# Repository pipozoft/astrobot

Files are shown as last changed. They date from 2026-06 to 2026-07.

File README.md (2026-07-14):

# Astrobot

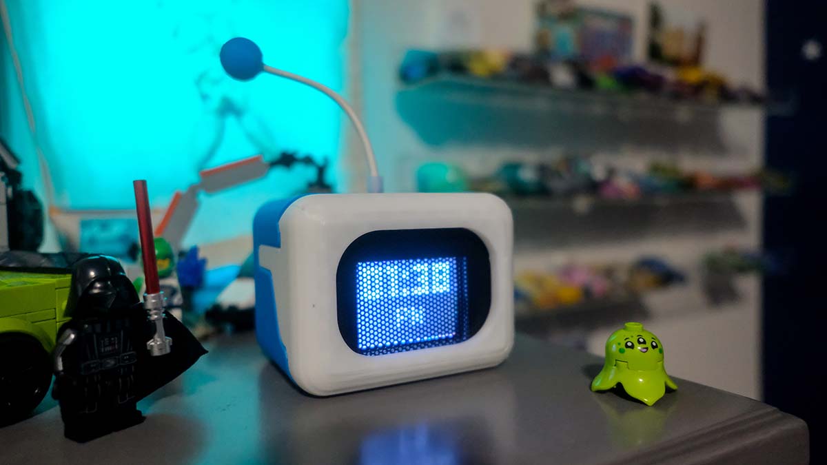
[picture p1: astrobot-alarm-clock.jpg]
Astrobot Alarm Clock


An expressive eye/display bot for the **Inland Nano** (Arduino Nano clone, ATmega328P) with a **1.8" ST7735 TFT**, **HW-084 DS1307 RTC**, and **vibration sensor**.

Cycles between animated pixel-art eyes, a digital clock, and a heartbeat animation on vibration.

## Features

- **Animated eyes** — 5-frame blink/wink sequence with smooth transitions
- **Digital clock** — HH:MM readout with colon blinking, synced from the DS1307 RTC
- **Vibration reaction** — SW-420 triggers a 13-frame heartbeat animation
- **Pixel-art graphics** — All sprites stored in PROGMEM via an external header

## Hardware

| Component | Qty |
|---|-----|
| Inland Nano (Arduino Nano clone) | 1 |
| HW-084 (DS1307 RTC with coin cell) | 1 |
| 1.8" 128×160 TFT (ST7735, 8-pin) | 1 |
| SW-420 vibration sensor | 1 |

See [docs/WIRING_GUIDE.md](docs/WIRING_GUIDE.md) for the full wiring table, pin-reassignment rationale, and enclosure notes.

## Dependencies

Install these via the Arduino Library Manager:

- [Adafruit GFX](https://github.com/adafruit/Adafruit-GFX-Library)
- [Adafruit ST7735](https://github.com/adafruit/Adafruit-ST7735-Library)
- [RTClib](https://github.com/adafruit/RTClib)

## Upload

1. Open `astrobot_hw084.ino` in the Arduino IDE.
2. Select **Tools → Board → Arduino Nano** (or Inland Nano).
3. Select the correct **Processor** (ATmega328P, Old Bootloader if needed).
4. Select the port and upload.

## Project Structure

```
astrobot_hw084/
├── astrobot_hw084.ino      # Main sketch
├── pixel_data.h            # All 23 eye/heart frames as PROGMEM arrays
├── notes.h                 # Pin mappings, constants, and notes
├── HOWITWORKS.md           # Under-the-hood explanation
├── README.md
├── .gitignore
├── 3d/
│   └── astrobot-final-version.3mf   # 3D-printable enclosure
├── docs/
│   └── WIRING_GUIDE.md     # Step-by-step build instructions
├── eyes/
│   ├── ImagesToCArray.py   # PNG → PROGMEM C array converter
│   ├── normal_eye/         # 5 normal eye animation frames (PNG)
│   │   ├── astrobot1-5.png
│   │   └── output.h
│   ├── heart_eye/          # 13 heart eye animation frames (PNG)
│   │   ├── astrobot11-23.png
│   │   └── output.h
│   └── .gitignore
└── music/
    ├── Light MIDI - Astro Bot Theme.mid
    └── Light MIDI - Astro Bot Theme.mp3
```

## Credit

Project based on [Astrobot Clock](https://github.com/Birdy-C/Puzzle-with-3D-Printer/tree/main/Astrobot%20Clock)

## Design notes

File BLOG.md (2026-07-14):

# Building Astrobot: An Arduino Alarm Clock With Personality

Astrobot Alarm Clock

*A gift for my son that became a deep dive into embedded programming, pixel art on a 128x160 screen, and making magic with $25 of parts.*

---

## Why I Built This

My son loves the Astrobot character from the game — the little expressive robot with the big eyes. You can't buy this anywhere. So when I stumbled across [Birdy-C's Astrobot Clock](https://github.com/Birdy-C/Puzzle-with-3D-Printer/tree/main/Astrobot%20Clock) on GitHub, I knew it was the perfect project to build together.

I've built Arduino projects before, so this wasn't my first rodeo. But this one was different — it wasn't just about making something work. It was about making something *charming*. A little bot that looks around, blinks, shows the time, and beats its heart when you knock on it. The kind of thing my son could put on his nightstand and actually want to keep.

I ordered the parts from Microcenter and Amazon, 3D-printed the enclosure, and started hacking.

## What It Is

Astrobot is a small desktop bot with a 1.8" TFT screen as its face. It runs on an Arduino Nano (well, an Inland Nano clone — $8 at Microcenter) and cycles between:

- **Animated eyes** — pixel-art eyes that blink and look left/right
- **A digital clock** — reads the current time from a real-time clock module
- **A heartbeat animation** — when you knock on it, the screen shows beating hearts and plays a melody

There's also an alarm mode that loops the melody at a configurable time. All of this in a 3D-printed enclosure that looks like a little robot head.

### The Parts

| Component | Cost |
|---|---|
| [Inland Nano (ATmega328P)](https://www.microcenter.com/product/615097/inland-nano-development-board-arduino-compatible) | ~$8 |
| 1.8" ST7735 TFT (128x160) | ~$5 |
| HW-084 DS1307 RTC (with CR2032) | ~$3 |
| SW-420 vibration sensor | ~$2 |
| [Adafruit Mini Speaker (1.5W 8 ohm)](https://www.adafruit.com/product/1891) | ~$5 |
| **Total** | **~$23-28** |

All sourced from Microcenter and Amazon. No soldering required if you use a breadboard, or the right wires, though I ended up soldering the speaker wires for a cleaner build.

## How It Works: The Architecture

The entire sketch is built around a **non-blocking state machine** — no `delay()` calls anywhere. This is the single most important design decision in the project, and it's what makes everything feel smooth and responsive.

### The Four States

```
SHOW_EYES  <-->  SHOW_DATE  <-->  VIBRATION_DETECTED  <-->  ALARMING
```

1. **SHOW_EYES** (default) — Displays animated eyes for ~10 seconds. The eyes blink, look left, look right, with random pauses between expressions.

2. **SHOW_DATE** — Renders the current time in 12-hour format with AM/PM. Reads from the DS1307 RTC over I2C. Lasts ~5 seconds.

3. **VIBRATION_DETECTED** — Triggered when the SW-420 sensor fires. Plays a melody and shows a 13-frame beating heart animation.

4. **ALARMING** — When the configured alarm time hits, loops the melody continuously until dismissed by a knock or 60-second timeout.

Each state runs for a set duration using `millis()`, then transitions to the next. The melody player, animation system, and clock display all operate independently — nothing blocks anything else.

### The Pixel Rendering System

This is where it gets interesting. The ATmega328P has **2KB of RAM**. You can't store full animation frames in RAM — a single 128x160 1-bit frame would be 2,560 bytes. More than the entire RAM.

The solution: store everything in **PROGMEM** (flash memory) and render using **diff-based animation**.

Each animation frame is stored as two arrays:
- `white_pixels` — coordinates of pixels to turn ON
- `black_pixels` — coordinates of pixels to turn OFF

Instead of redrawing the entire screen each frame, the renderer only touches the pixels that *changed* between frames. This means each animation step might only draw 5-20 pixels instead of thousands.

Here's what a frame looks like in `pixel_data.h`:

```c
static const PROGMEM byte white_pixels_astrobot1[] = {
  34,3, 35,3, 36,3, 37,3, 38,3, 39,3,  // coordinates of pixels to light up
  // ... more x,y pairs
};
static const byte * const white_pixels[] PROGMEM = { white_pixels_astrobot1, white_pixels_astrobot2, /* ... */ };
```

The Python script `eyes/ImagesToCArray.py` does the heavy lifting — it takes a sequence of PNG sprite frames, computes the pixel diffs between consecutive frames, and outputs the C arrays. I just had to create the pixel art in Aseprite, export the frames, and run the script.

### Eye Mirroring

The bot has two eyes, but I only store one eye's worth of animation data. The right eye is drawn by taking the left eye's pixel coordinates and offsetting them by 80 pixels (x + 80 on the 128px-wide screen).

For the "looking left" vs "looking right" effect, the `_INVERT` variant mirrors the left eye by computing `77 - x`, flipping the eye horizontally. It's a clever trick that halves the data storage needed.

### The Melody Player

The melody is its own mini state machine. Each note in the melody is defined as:

```c
{ frequency_Hz, note_duration_ms, rest_duration_ms }
```

The `updateMelody()` function runs every `loop()` iteration, checking elapsed time against the current note's duration. No blocking, no delays — the melody plays alongside everything else.

The melody itself was converted from a MIDI file of the "Astro Bot Theme" using [ShivamJoker's MIDI-to-Arduino converter](https://github.com/ShivamJoker/MIDI-to-Arduino). Just drop the MIDI in, get a C array out.

## The Challenges

### Challenge 1: Pin Conflicts

The Arduino Nano has limited pins. The TFT display needs SPI (SCLK, MOSI, CS, DC, RES), and the DS1307 RTC needs I2C (SDA, SCL on A4/A5). Problem: the hardware SPI pins overlap with the I2C bus.

**Solution:** Use software SPI on analog pins A1 (SCLK) and A2 (MOSI), freeing up A4/A5 for I2C. The TFT's CS pin moved from A5 to D2, and RES from A4 to D5. It's slower than hardware SPI, but at 128x160 with diff-based rendering, you don't need the speed.

### Challenge 2: Memory Constraints

2KB of RAM. That's it. Every byte counts.

- All pixel data lives in PROGMEM (flash), not RAM
- The font data is stored in PROGMEM via Adafruit GFX's `PROGMEM` support
- Even the melody array lives in flash
- The state machine avoids large local variables or stack-heavy function calls

The diff-based rendering system was the key insight. Instead of buffering an entire frame, only the changed pixels are processed each cycle. This keeps peak RAM usage well under the limit.

### Challenge 3: Animation Smoothness

Getting smooth animation on a 128x160 TFT with software SPI required careful timing. The frame rate depends on how many pixels change between frames, which varies. The diff-based approach helps — a blink animation might only change 30 pixels, while a full eye movement might change 100+.

The trick was balancing animation complexity against the SPI transfer time. More pixels = slower frame rate. The 5-frame blink and 13-frame heartbeat sequences were designed to be light enough for smooth playback.

### Challenge 4: 3D Printing the Enclosure

The enclosure files came from the [original project](https://github.com/Birdy-C/Puzzle-with-3D-Printer/tree/main/Astrobot%20Clock) — I didn't design this one myself. Instead of buying a printer or fiddling with settings, I found a local non-profit that offers 3D printing services. I got to support them and walk away with a clean print, no headaches involved. Sometimes the best tool is the one you don't have to own.

## The Code

The entire project lives in a single `.ino` file (`astrobot_hw084.ino`, ~520 lines) with supporting header files. Here's the high-level flow:

```cpp
void setup() {
  // Init TFT, RTC, vibration sensor, speaker
  // Load animation pointers from pixel_data.h
  // Sync time from DS1307
}

void loop() {
  unsigned long now = millis();
  
  updateMelody();          // Advance melody if playing
  readVibration();         // Check for knocks
  
  switch (currentState) {
    case SHOW_EYES:
      updateEyes(now);     // Draw eye animation frames
      if (now - stateStart > 10000) transitionTo(SHOW_DATE);
      break;
      
    case SHOW_DATE:
      updateClock(now);    // Render time from RTC
      if (now - stateStart > 5000) transitionTo(SHOW_EYES);
      break;
      
    case VIBRATION_DETECTED:
      updateHeart(now);    // Draw heart animation
      if (!melodyPlaying) transitionTo(SHOW_EYES);
      break;
      
    case ALARMING:
      updateClock(now);    // Show time in red
      updateMelody();      // Loop melody
      break;
  }
}
```

Everything runs on `millis()` timers. The animation frames advance at their own pace, the melody has its own timer, and the state transitions happen independently. This non-blocking design is what makes the bot feel alive — it's always doing something, never frozen waiting.

## What I'd Do Differently

If I built this again:

1. **Use hardware SPI for the TFT** — I'd pick a board with enough SPI-capable pins that don't conflict with I2C. The software SPI works but it's the bottleneck for frame rate.

2. **Add more animation frames** — The 5-frame blink is charming, but more frames would make it smoother. The PROGMEM approach scales well here.

3. **Consider an ESP32** — More RAM, more processing power, WiFi for NTP time sync instead of a dedicated RTC module. But that defeats the "$25 parts" constraint.

## What My Son Learned

Beyond the finished product, this project was about introducing him to the idea that you can *make things*. Not just download an app or buy a toy — but design something, code it, solder it, print it, and have a physical object that you built from scratch.

## Resources

- **Source code:** [GitHub - pipozoft/astrobot](https://github.com/pipozoft/astrobot)
- **Based on:** [Birdy-C's Astrobot Clock](https://github.com/Birdy-C/Puzzle-with-3D-Printer/tree/main/Astrobot%20Clock)
- **Arduino libraries:** [Adafruit GFX](https://github.com/adafruit/Adafruit-GFX-Library), [Adafruit ST7735](https://github.com/adafruit/Adafruit-ST7735-Library), [RTClib](https://github.com/adafruit/RTClib)
- **MIDI converter:** [ShivamJoker/MIDI-to-Arduino](https://github.com/ShivamJoker/MIDI-to-Arduino)

---

*Built with love, frustration, and a lot of troubleshooting on a Saturday afternoon. If you build your own, share it — I'd love to see what expressions you come up with.*

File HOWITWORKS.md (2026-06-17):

# Astrobot — How It Works

## What is Astrobot?

Astrobot is an animated display bot with expressive pixel-art eyes, a digital clock, vibration-reactive hearts, a speaker melody, and alarm clock features. It runs on an **Inland Nano** (an Arduino Nano clone) and uses a 1.8" TFT screen as its face. Most of the time it shows animated eyes that blink and look around. Every few seconds it switches to a digital clock display. If you knock on its enclosure, it plays a MIDI-converted melody while showing a beating heart animation. It can also wake you up at a configurable time with a looping alarm melody.

---

## Hardware at a glance

| Component | Role |
|---|---|
| **Inland Nano** | The brain. Runs the Arduino sketch, drives the display, reads the sensor, and plays sounds. |
| **HW-084 / DS1307 RTC** | The clock module. Keeps accurate time even when power is off thanks to a CR2032 coin cell battery. Communicates over I2C. |
| **1.8" ST7735 TFT** | The face. A 128x160 pixel color display that shows eyes, time, and hearts. |
| **SW-420 vibration sensor** | The ears. Detects knocks or taps on the enclosure so Astrobot can react. |
| **8 ohm 0.25W speaker + 100 ohm resistor** | The voice. Plays the melody when knocked or when the alarm goes off. The resistor limits current to protect the Nano's pin. |

**Wiring note**: The TFT uses software SPI on analog pins A1 (SCLK) and A2 (MOSI) instead of the hardware SPI pins. This frees up A4 and A5 for the RTC's I2C bus so both devices can work together without conflict.

---

## How the software works

The code runs a simple **state machine** that rotates through three states: eyes, clock, and vibration (hearts + melody). Each pass through `loop()` reads the vibration sensor, checks the RTC time, and decides which state to show.

### The state machine

- **Eyes state** — The default "idle" animation. Astrobot shows pixel-art eyes that blink and look left/right at random intervals (1--10 seconds between blinks). Each eye frame is drawn by plotting individual pixels from arrays stored in PROGMEM (flash memory) so they don't eat up the Nano's limited RAM. The eyes are mirrored across both sides of the screen.

- **Clock state** — After about 10 seconds of eyes, the code switches to a digital clock. The time is displayed in 12-hour format with a monospace font (Adafruit 5x7 at size 3), centered on the screen, amber-colored (255, 186, 31). After 5 seconds it flips back to eyes.

- **Hearts + Melody state (vibration)** — When the vibration sensor reading on A7 exceeds the threshold (default 500), the code jumps into this state. It clears the screen, starts playing the melody via `tone()`, and runs a heart-beating animation. It stays here until the melody finishes playing, then returns to eyes.

### Everything is non-blocking

The whole sketch avoids `delay()` entirely. Instead it uses `millis()` timers to track when things should happen. This means:

- The melody can keep playing while the hearts continue animating
- The state machine can switch states cleanly without freezing
- Multiple timers can run in parallel (animation frames, melody notes, state transitions)

The melody player is a mini state machine of its own. It tracks which note is playing, when that note started, and whether it's in the "sound" phase or the "silent gap" phase. Each `loop()` call to `updateMelody()` checks the elapsed time and advances to the next note or rest when the current phase is done.

---

## Features

### Clock
- 12-hour format with leading zeros (e.g., "09:05" not "9:5")
- AM/PM indicator
- Centered on the 128x160 screen using calculated offsets
- Amber color (`rgb(255, 186, 31)`) via `tft.color565()`
- Monospace font (Adafruit 5x7) at text size 3 for the digits, size 2 for the AM/PM label

### Eyes
- 16-frame animation sequence covering blink and look-left / look-right movements
- Frame 0 is the default "open" state — pauses for 1--10 seconds (random)
- Frames 1--4: eyes close downward (blink)
- Frames 5--8: eyes open back upward
- Frames 9--15: mirrored version of the blink sequence for looking right
- Each frame draws only the pixels that changed from the previous frame (uses separate "white" and "black" pixel arrays for additive/subtractive drawing)
- Pixel data stored in PROGMEM via `pgm_read_byte()`

### Vibration reaction
- Reads analog value on pin A7
- Threshold is configurable (default 500)
- When triggered: jumps to `VIBRATION_DETECTED` state
- Shows a 13+ frame beating heart animation (frames ramp up through heart sizes, then pulse)
- Starts the melody via `startMelody()`
- Returns to eyes when the melody finishes

### Melody
- Non-blocking player that converts MIDI note data into `tone()` calls
- Each note entry has three values: frequency (Hz), note duration (ms), and rest duration (ms)
- The player advances through notes by checking `millis()` against `melodyPhaseStart`
- Two-phase playback per entry: sound phase (tone on), then rest phase (silent gap)
- Plays during vibration state and alarm state
- Automatically stopped when exiting either state

### Alarm
- Configurable wake-up time (hour and minute)
- Weekday-only mode (skips alarm on weekends)
- When triggered: shows the time in red with an "ALARM" label
- Plays the melody on a loop until dismissed
- Dismissed by vibration (knock on the enclosure)
- Auto-off after 60 seconds if not dismissed

---

## Configuration reference

All of these are `#define` constants near the top of `astrobot_hw084.ino`:

| Constant | Values | Default | What it does |
|---|---|---|---|
| `ALARM_ENABLED` | `true` / `false` | `true` | Enables or disables the alarm feature entirely |
| `ALARM_HOUR` | `0` -- `23` | `7` | The hour the alarm triggers (24-hour format) |
| `ALARM_MINUTE` | `0` -- `59` | `0` | The minute the alarm triggers |
| `WEEKDAYS_ONLY` | `true` / `false` | `true` | If `true`, alarm only fires Monday through Friday |
| `THRESHOLD` | `0` -- `1023` | `500` | Vibration sensitivity. Lower = more sensitive. |
| `SPEAKER_PIN` | Any digital pin | `11` | The pin connected to the speaker (via 100 ohm resistor) |
| `stateChangeIntervalTimer` | milliseconds | `5000` | How long the clock stays visible before switching back to eyes |
| `stateChangeIntervalEye` | milliseconds | `10000` | How long the eyes stay visible before switching to clock |

To change these, edit the `#define` lines and re-upload to the Nano.

---

## Pin reference

| Component | Signal | Nano Pin |
|---|---|---|
| **TFT** | CS | D2 |
| TFT | RST | D5 |
| TFT | DC | A3 |
| TFT | MOSI (data) | A2 |
| TFT | SCLK (clock) | A1 |
| TFT | BL (backlight) | A0 |
| **RTC (DS1307)** | SDA | A4 |
| RTC | SCL | A5 |
| **Vibration sensor** | OUT (analog) | A7 |
| **Speaker** | Positive (via 100 ohm) | D11 |
| Speaker | Negative | GND |

The TFT uses software SPI (bit-banged) on A1/A2. The RTC uses the hardware I2C bus on A4/A5. These don't interfere with each other.

---

## The non-blocking pattern

The entire sketch is built around `millis()` rather than `delay()`. Here's how each timer works:

```
loop():
  1. Call updateMelody()  -- advances melody if current note/rest is done
  2. Read vibration sensor
  3. Check state-change timers
  4. If state changed:
     - Stop any previous melody
     - Clear screen
     - Start new state (play melody, draw first eye frame, etc.)
  5. If animation interval has elapsed:
     - Advance to next frame (eyes or hearts)

  All of this happens in under a few milliseconds, then loop() runs again.
  The melody keeps playing while frames keep animating.
```

**Melody timing** (from `notes.h`):

```cpp
// Each entry: { frequency (Hz), note duration (ms), rest duration (ms) }
{ Ab3, 462, 0 },  // play Ab3 for 462ms, no rest afterward
{ Ab2, 115, 115 } // play Ab2 for 115ms, then rest 115ms
```

The `updateMelody()` function at line 268 of `astrobot_hw084.ino` tracks:
- `melodyIndex` — which note we're on
- `melodyPhaseStart` — when the current phase began
- `melodyPlaying` — whether we're in the tone phase or the rest phase

When a phase's duration elapses, the function either advances to the rest phase or moves to the next note. When all notes are done, `melodyActive` is set to `false` and playback stops.

This same pattern is used everywhere in the code: set a target time, check if it has passed, act if so. No blocking, no freezing, everything stays in sync.

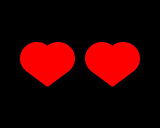
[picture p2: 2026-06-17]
eyes/heart_eye/astrobot22.png

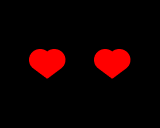
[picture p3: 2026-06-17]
eyes/heart_eye/astrobot16.png

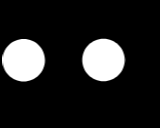
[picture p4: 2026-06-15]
eyes/normal_eye/astrobot5.png

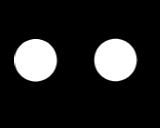
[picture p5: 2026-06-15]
eyes/normal_eye/astrobot2.png

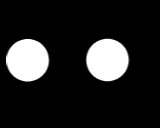
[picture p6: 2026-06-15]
eyes/normal_eye/astrobot4.png

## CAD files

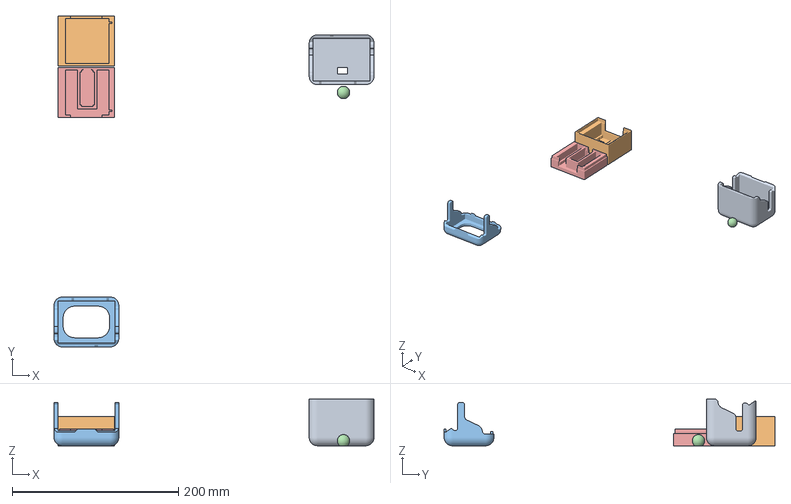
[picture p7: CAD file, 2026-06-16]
3d/astrobot-final-version.3mf
385.2 x 398.2 x 56.1 mm
outside-blue
inside-top
outside-white
outside-blueball
inside-bottom

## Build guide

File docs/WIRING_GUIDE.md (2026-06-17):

# Astrobot — Wiring Guide

## Overview

Astrobot is an animated eye/display bot built on an **Inland Nano** (Arduino Nano
clone, ATmega328P). It shows expressive pixel-art eyes, a digital clock, and
reacts to vibration with a heart animation.

## Bill of Materials

| Component | Description |
|---|---|
| Inland Nano | Arduino Nano-compatible dev board (ATmega328P @ 16MHz) |
| HW-084 | DS1307 RTC module with coin cell backup (I2C) |
| 1.8" TFT LCD | 128×160 RGB display, ST7735 driver, 8-pin header |
| Vibration sensor | SW-420 or similar — digital/analog vibration switch |
| 8Ω 0.25W speaker | Adafruit "Thin Plastic Speaker w/Wires" — plays melody on vibration |
| 100Ω resistor | Current-limiter for speaker (protects Nano pin and speaker coil) |
| USB power cable | Micro-USB for Nano |
| Hookup wire | Female-to-female dupont, ~12 wires |
| 3D printed enclosure | Custom housing for all components |

### TFT module pinout (label order on module)

```
GND VCC SCL SDA RES DC CS BL
```

## Wiring Table

### TFT LCD (to Nano)

| TFT Module | Nano Pin | Cable Color |
|---|---|---|
| GND | GND | Black |
| VCC | 3.3V *(use 3.3V, not 5V, for the ST7735)* | Red |
| SCL | A1 | Yellow |
| SDA | A2 | Green |
| RES | D5 | Blue |
| DC | A3 | Orange |
| CS | D2 | Purple |
| BL | A0 | White |

### HW-084 RTC (DS1307, to Nano)

| HW-084 | Nano Pin | Cable Color |
|---|---|---|
| GND | GND | Black |
| VCC | 5V | Red |
| SDA | A4 | Yellow |
| SCL | A5 | Green |

### Vibration Sensor (to Nano)

| Sensor | Nano Pin | Cable Color |
|---|---|---|
| GND | GND | Black |
| VCC | 5V | Red |
| OUT (DO) | A7 | Orange |

### Speaker (to Nano)

| Speaker | Nano Pin | Cable Color |
|---|---|---|
| (+) lead | D11 *(via 100Ω resistor)* | Blue |
| (−) lead | GND | Black |

**Important**: Wire the 100Ω resistor in series with the speaker's positive lead.
Without it, the 8Ω coil draws ~625 mA peak from the Nano pin (far above the 40 mA
maximum). The resistor limits current to ~31 mA and prevents damaging the pin or
the 0.25W speaker coil.

## Why These Pin Assignments?

The original design used a DS1302 RTC (SPI-like, ThreeWire library). The
HW-084 module uses a **DS1307** RTC which communicates over **I2C** on pins
**A4 (SDA)** and **A5 (SCL)**.

In the original wiring, the TFT's RES and CS pins were on A4 and A5 — which
would conflict with I2C. The fix:

- **TFT RES moved** from A4 → D5
- **TFT CS moved** from A5 → D2
- A4 and A5 are now free for the RTC's I2C bus

The TFT uses **software SPI** (bit-banged) on A1 (SCLK) and A2 (MOSI),
which works with any pins — no hardware SPI is required.

## Step-by-Step Assembly

### 1. Prepare the Nano

Place the Nano in the enclosure or on a breadboard. Identify the pin headers:

```
                         USB port (top)
  ┌──────────────────────────────────────────┐
  │ D12  D13  VIN  RST   A0  A1  A2  A3  A4 │
  │ D11  D10  D9   D8   D7  D6  D5  D4  D3  │
  │         GND  AREF  D2  D1  D0           │
  └──────────────────────────────────────────┘
                         USB port
```

### 2. Connect the TFT Display

1. **GND → GND** — any Nano GND pin (there are 3)
2. **VCC → 3.3V** — the ST7735 runs at 3.3V logic, do not use 5V here
3. **SCL → A1** — SPI clock (software bitbang)
4. **SDA → A2** — SPI data (MOSI)
5. **RES → D5** — Reset line
6. **DC → A3** — Data/Command select
7. **CS → D2** — Chip Select
8. **BL → A0** — Backlight control (code drives this HIGH on boot)

Keep wires short where possible to reduce signal noise on the display.

### 3. Connect the HW-084 RTC

1. Connect **GND → GND** (same ground rail as Nano)
2. Connect **VCC → 5V** (the HW-084 module uses 5V)
3. Connect **SDA → A4** (I2C data line)
4. Connect **SCL → A5** (I2C clock line)

Make sure the CR2032 battery is installed in the HW-084 holder. This keeps the
time when power is off.

**Note**: The HW-084 module commonly has pull-up resistors for the I2C bus, so
external pull-ups are not needed.

### 4. Connect the Vibration Sensor

1. **GND → GND**
2. **VCC → 5V** (most SW-420 modules work at 5V)
3. **DO (digital out) → A7**

Some vibration modules have an AO (analog out) pin. The code uses analog read
(A7) so either DO or AO works. If using DO, the threshold might need
adjustment — see the `THRESHOLD` define in the code.

### 5. Connect the Speaker

1. Solder or twist the **100Ω resistor** to the speaker's **positive** (usually
   red) wire
2. Connect the free end of the resistor → **D11**
3. Connect the speaker's **negative** (usually black) wire → **GND**

```
Nano D11 ─── 100Ω ─── Speaker(+) ─── Speaker(−) ─── GND
```

The 100Ω resistor is essential — without it the 8Ω coil would draw ~625 mA
peak from the Nano pin (ATmega328P max is 40 mA). The resistor limits current
to ~31 mA, which is safe for both the pin and the 0.25W speaker.

### 6. Connect Power

The Nano is powered via its micro-USB port. 5V and GND from the Nano's
regulator feed the RTC and vibration sensor. The TFT uses the 3.3V rail from
the Nano's onboard regulator.

### 7. Verify Continuity

Before plugging in USB, double-check with a multimeter:

- No shorts between VCC and GND on any module
- 3.3V pin measures ~3.3V relative to GND
- A4 and A5 are not connected to anything except the RTC (they should not
  touch TFT wires)

## Power Budget

| Component | Typical Current |
|---|---|
| Inland Nano (idle) | ~15 mA |
| ST7735 TFT (active) | ~30 mA |
| HW-084 RTC | ~1 mA |
| Vibration sensor | ~1 mA |
| 8Ω speaker (active) | ~5 mA (via 100Ω resistor) |
| **Total** | **~52 mA** |

Well within the Nano's USB power budget (500 mA). No external power supply
needed.

## Code Upload

1. Install the required libraries via Arduino Library Manager:
   - `Adafruit GFX Library` (by Adafruit)
   - `Adafruit ST7735 Library` (by Adafruit)
   - `RTClib` (by Adafruit)

2. Open `astrobot_hw084.ino` in the Arduino IDE

3. Select **Board: Arduino Nano**, **Processor: ATmega328P (Old Bootloader)**
   if using a clone, or **ATmega328P** for official Nanos. Inland Nanos
   typically need **Old Bootloader**.

4. Select the correct **Port**

5. Click **Upload**

## 3D Printed Enclosure Notes

When designing or printing the enclosure, consider:

- Leave ventilation gaps near the Nano's voltage regulator (it gets warm)
- The TFT should be recessed so the glass sits flush with the enclosure face
- The HW-084 needs access for the CR2032 battery — add a removable hatch or
  slot
- The vibration sensor should be mounted firmly so it picks up knocks on the
  enclosure wall
- Leave a hole for the micro-USB port
- Cable channels help keep wires tidy inside

## Troubleshooting

| Symptom | Likely Cause |
|---|---|
| TFT blank/white | No power to TFT VCC; check 3.3V connection |
| TFT flickers | Loose CS or RES wire; check D2 and D5 |
| No time shown | HW-084 not connected; check A4/A5/SDA/SCL |
| Wrong time after power off | CR2032 battery missing or dead in HW-084 |
| Vibration not detected | Sensor GND not connected; threshold too high (`THRESHOLD`) |
| No sound from speaker | Resistor missing or speaker ± reversed; check D11 connection |
| Speaker sounds distorted/noisy | Missing 100Ω series resistor (overloading pin); or melody data issue |
| Won't upload | Wrong bootloader setting; try "Old Bootloader" |

## Code Reference

Key pin defines (from `astrobot_hw084.ino`):

```cpp
#define TFT_CS   2   // LCD chip select
#define TFT_RST  5   // LCD reset
#define TFT_DC   A3  // LCD data/command
#define TFT_MOSI A2  // LCD SPI data
#define TFT_SCLK A1  // LCD SPI clock
#define TFT_BL   A0  // LCD backlight

#define SPEAKER_PIN 11          // Melody output (via 100Ω resistor to speaker)

#define VIBRATION_SENSOR A7  // Vibration sensor analog input
#define THRESHOLD 500        // Vibration detection threshold

// RTC (DS1307) uses I2C: SDA=A4, SCL=A5
```

## Revision History

- **HW-084 revision** — Switched from DS1302 (ThreeWire) to DS1307 (I2C)
  via RTClib. TFT CS/RES moved off A4/A5 to free the I2C bus.
- **Modern TFT revision** — Replaced UTFT library with Adafruit_ST7735 +
  Adafruit_GFX for standard library compatibility.

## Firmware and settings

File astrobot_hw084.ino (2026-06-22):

// Astrobot — animated display bot
// Eyes, clock, vibration-reactive hearts, speaker melody, and alarm clock.
// State machine cycles between SHOW_EYES, SHOW_DATE, VIBRATION_DETECTED, ALARMING.

#include <SPI.h>
#include <Wire.h>
#include <Adafruit_GFX.h>
#include <Adafruit_ST7735.h>
#include <RTClib.h>
#include "Micro5_Clock.h"
#include "pixel_data.h"
#include "notes.h"

// ============================================================
// Configuration — adjust these to change behavior
// ============================================================

// Alarm clock
#define ALARM_ENABLED   true
#define ALARM_HOUR      7
#define ALARM_MINUTE    30
#define WEEKDAYS_ONLY   true

// Vibration sensor
#define VIBRATION_SENSOR A7
#define THRESHOLD 500

// ============================================================
// Pin assignments
// ============================================================

// TFT display (1.8" ST7735, software SPI)
#define TFT_CS   2
#define TFT_RST  5
#define TFT_DC   A3
#define TFT_MOSI A2
#define TFT_SCLK A1
#define TFT_BL   A0

// Speaker (8 ohm 0.25W via 100 ohm resistor)
#define SPEAKER_PIN 11

// RTC (DS1307) uses I2C: SDA=A4, SCL=A5

RTC_DS1307 rtc;
Adafruit_ST7735 tft(TFT_CS, TFT_DC, TFT_MOSI, TFT_SCLK, TFT_RST);

#define countof(a) (sizeof(a) / sizeof(a[0]))

// ============================================================
// State machine — each state shows a different "mood"
// ============================================================

enum State {
  SHOW_EYES,          // Animated pixel-art eyes (default state)
  SHOW_DATE,          // Digital 12h clock, amber text
  VIBRATION_DETECTED, // Heart animation + melody when knocked
  ALARMING            // Alarm triggered — red time + looping melody
};

// ============================================================
// RTC setup — syncs time on first boot
// ============================================================

void setupRtc() {
  Serial.print("compiled: ");
  Serial.print(__DATE__);
  Serial.println(__TIME__);

  if (!rtc.begin()) {
    Serial.println("RTC not found! Check A4/A5");
    while (1) delay(10);
  }

  if (!rtc.isrunning()) {
    Serial.println("RTC stale! Setting from compile time");
    rtc.adjust(DateTime(__DATE__, __TIME__));
  } else {
    DateTime now = rtc.now();
    DateTime compiled = DateTime(__DATE__, __TIME__);
    if (now < compiled) {
      Serial.println("RTC behind — updated to computer time");
      rtc.adjust(compiled);
    }
  }
}

// ============================================================
// TFT setup — initializes the display
// ============================================================

void setupLCD() {
  pinMode(TFT_BL, OUTPUT);
  digitalWrite(TFT_BL, HIGH);
  tft.initR(INITR_BLACKTAB);
  tft.setRotation(1);
  tft.fillScreen(ST7735_BLACK);
}

void setup() {
  Serial.begin(9600);
  randomSeed(analogRead(0));
  setupRtc();
  setupLCD();
}

// ============================================================
// Pixel drawing helpers — render eye/heart frames from PROGMEM
// ============================================================

#define PROCESS_PIXEL_ARRAY(array) process_pixel_array(array, sizeof(array) / sizeof(array[0]))
#define PROCESS_PIXEL_ARRAY_DOUBLE(array) process_pixel_array_double(array, sizeof(array) / sizeof(array[0]))
#define PROCESS_PIXEL_ARRAY_DOUBLE_INVERT(array) process_pixel_array_double_invert(array, sizeof(array) / sizeof(array[0]))

uint16_t currentColor;

void setColor(uint16_t c) { currentColor = c; }

void process_pixel_array(unsigned char pixels[][2], int size) {
  for (int i = 0; i < size; i++) {
    int x = pgm_read_byte(&pixels[i][0]);
    int y = pgm_read_byte(&pixels[i][1]);
    tft.drawPixel(x, y, currentColor);
  }
}

// Draw the same frame on both eyes (left eye, right eye shifted +80)
void process_pixel_array_double(unsigned char pixels[][2], int size) {
  for (int i = 0; i < size; i++) {
    int x = pgm_read_byte(&pixels[i][0]);
    int y = pgm_read_byte(&pixels[i][1]);
    tft.drawPixel(x, y, currentColor);
    tft.drawPixel(x + 80, y, currentColor);
  }
}

// Same but left eye is mirrored horizontally
void process_pixel_array_double_invert(unsigned char pixels[][2], int size) {
  for (int i = 0; i < size; i++) {
    int x = 77 - pgm_read_byte(&pixels[i][0]);
    int y = pgm_read_byte(&pixels[i][1]);
    tft.drawPixel(x, y, currentColor);
    tft.drawPixel(x + 80, y, currentColor);
  }
}

// ============================================================
// Color helpers — eye amber, heart blue, black (erase)
// ============================================================

unsigned long animation_interval = 200;

void setBlackColor()   { setColor(ST7735_BLACK); }
void setEyeColor()     { setColor(ST7735_BLUE); }
void setHeartColor()   { setColor(tft.color565(255, 0, 0)); }

// ============================================================
// Clock display — 12h format, monospace (Adafruit 5x7), centered
// ============================================================

void printDate(const DateTime& dt) {
  uint8_t h12 = dt.hour() % 12;
  if (h12 == 0) h12 = 12;
  char t[6];
  t[0] = '0' + h12 / 10;
  t[1] = '0' + h12 % 10;
  t[2] = ':';
  t[3] = '0' + dt.minute() / 10;
  t[4] = '0' + dt.minute() % 10;
  t[5] = '\0';

  tft.setFont(&Micro5_Clock);
  tft.setTextColor(ST7735_WHITE, ST7735_BLACK);
  tft.setTextSize(1);

  tft.setCursor(10, 60);
  tft.print(t);

  tft.setFont(NULL);
  tft.setTextSize(4);
  tft.setCursor(60, 80);
  tft.print(dt.hour() < 12 ? "AM" : "PM");
}

#if ALARM_ENABLED
void printAlarm(const DateTime& dt) {
  uint8_t h12 = dt.hour() % 12;
  if (h12 == 0) h12 = 12;
  char t[6];
  t[0] = '0' + h12 / 10;
  t[1] = '0' + h12 % 10;
  t[2] = ':';
  t[3] = '0' + dt.minute() / 10;
  t[4] = '0' + dt.minute() % 10;
  t[5] = '\0';

  tft.setFont(&Micro5_Clock);
  tft.setTextColor(ST7735_RED, ST7735_BLACK);
  tft.setTextSize(1);

  tft.setCursor(10, 60);
  tft.print(t);

  tft.setFont(NULL);
  tft.setTextSize(4);
  tft.setCursor(60, 80);
  tft.print(dt.hour() < 12 ? "AM" : "PM");
}
#endif

// ============================================================
// Eye animation — blink/look sequences
// ============================================================

int drawEyes(int frame) {
  int step = frame % 16;

  animation_interval = 500;

  if (step == 0) {
    tft.fillRect(0, 35, 160, 50, ST7735_BLACK);
    setEyeColor();
    PROCESS_PIXEL_ARRAY_DOUBLE(white_pixels_astrobot1);
    animation_interval = random(1000, 10000);
  } else if (step == 1 || step == 7) {
    setEyeColor(); PROCESS_PIXEL_ARRAY_DOUBLE(white_pixels_astrobot2);
    setBlackColor(); PROCESS_PIXEL_ARRAY_DOUBLE(black_pixels_astrobot2);
  } else if (step == 2 || step == 6) {
    setEyeColor(); PROCESS_PIXEL_ARRAY_DOUBLE(white_pixels_astrobot3);
    setBlackColor(); PROCESS_PIXEL_ARRAY_DOUBLE(black_pixels_astrobot3);
  } else if (step == 3 || step == 5) {
    setEyeColor(); PROCESS_PIXEL_ARRAY_DOUBLE(white_pixels_astrobot4);
    setBlackColor(); PROCESS_PIXEL_ARRAY_DOUBLE(black_pixels_astrobot4);
  } else if (step == 4) {
    setEyeColor(); PROCESS_PIXEL_ARRAY_DOUBLE(white_pixels_astrobot5);
    setBlackColor(); PROCESS_PIXEL_ARRAY_DOUBLE(black_pixels_astrobot5);
    animation_interval = random(1000, 4000);
  } else if (step == 5) {
    setEyeColor(); PROCESS_PIXEL_ARRAY_DOUBLE(black_pixels_astrobot4);
    setBlackColor(); PROCESS_PIXEL_ARRAY_DOUBLE(white_pixels_astrobot4);
  } else if (step == 6) {
    setEyeColor(); PROCESS_PIXEL_ARRAY_DOUBLE(black_pixels_astrobot3);
    setBlackColor(); PROCESS_PIXEL_ARRAY_DOUBLE(white_pixels_astrobot3);
  } else if (step == 7) {
    setEyeColor(); PROCESS_PIXEL_ARRAY_DOUBLE(black_pixels_astrobot2);
    setBlackColor(); PROCESS_PIXEL_ARRAY_DOUBLE(white_pixels_astrobot2);
  } else if (step == 8) {
    tft.fillRect(0, 35, 160, 50, ST7735_BLACK);
    setEyeColor();
    PROCESS_PIXEL_ARRAY_DOUBLE_INVERT(white_pixels_astrobot1);
    animation_interval = random(1000, 4000);
  } else if (step == 9 || step == 15) {
    setEyeColor(); PROCESS_PIXEL_ARRAY_DOUBLE_INVERT(white_pixels_astrobot2);
    setBlackColor(); PROCESS_PIXEL_ARRAY_DOUBLE_INVERT(black_pixels_astrobot2);
  } else if (step == 10 || step == 14) {
    setEyeColor(); PROCESS_PIXEL_ARRAY_DOUBLE_INVERT(white_pixels_astrobot3);
    setBlackColor(); PROCESS_PIXEL_ARRAY_DOUBLE_INVERT(black_pixels_astrobot3);
  } else if (step == 11 || step == 13) {
    setEyeColor(); PROCESS_PIXEL_ARRAY_DOUBLE_INVERT(white_pixels_astrobot4);
    setBlackColor(); PROCESS_PIXEL_ARRAY_DOUBLE_INVERT(black_pixels_astrobot4);
  } else if (step == 12) {
    setEyeColor(); PROCESS_PIXEL_ARRAY_DOUBLE_INVERT(white_pixels_astrobot5);
    setBlackColor(); PROCESS_PIXEL_ARRAY_DOUBLE_INVERT(black_pixels_astrobot5);
    animation_interval = random(1000, 4000);
  } else if (step == 13) {
    setEyeColor(); PROCESS_PIXEL_ARRAY_DOUBLE_INVERT(black_pixels_astrobot4);
    setBlackColor(); PROCESS_PIXEL_ARRAY_DOUBLE_INVERT(white_pixels_astrobot4);
  } else if (step == 14) {
    setEyeColor(); PROCESS_PIXEL_ARRAY_DOUBLE_INVERT(black_pixels_astrobot3);
    setBlackColor(); PROCESS_PIXEL_ARRAY_DOUBLE_INVERT(white_pixels_astrobot3);
  } else if (step == 15) {
    setEyeColor(); PROCESS_PIXEL_ARRAY_DOUBLE_INVERT(black_pixels_astrobot2);
    setBlackColor(); PROCESS_PIXEL_ARRAY_DOUBLE_INVERT(white_pixels_astrobot2);
  }

  return frame;
}

// ============================================================
// Heart animation — beating heart on vibration
// ============================================================

int drawHearts(int frame) {
  animation_interval = 200;
  int s = frame % 13;
  if (s == 0) {
    setHeartColor(); PROCESS_PIXEL_ARRAY_DOUBLE(white_pixels_astrobot11);
  } else if (s == 1) {
    setHeartColor(); PROCESS_PIXEL_ARRAY_DOUBLE(white_pixels_astrobot12);
  } else if (s == 2) {
    setHeartColor(); PROCESS_PIXEL_ARRAY_DOUBLE(white_pixels_astrobot13);
  } else if (s == 3) {
    setHeartColor(); PROCESS_PIXEL_ARRAY_DOUBLE(white_pixels_astrobot14);
  } else if (s == 4) {
    setHeartColor(); PROCESS_PIXEL_ARRAY_DOUBLE(white_pixels_astrobot15);
  } else if (s == 5) {
    setHeartColor(); PROCESS_PIXEL_ARRAY_DOUBLE(white_pixels_astrobot16);
  } else if (s == 6) {
    setHeartColor(); PROCESS_PIXEL_ARRAY_DOUBLE(white_pixels_astrobot17);
  } else if (s == 7) {
    setBlackColor(); PROCESS_PIXEL_ARRAY_DOUBLE(white_pixels_astrobot16);
  } else if (s == 8) {
    setBlackColor(); PROCESS_PIXEL_ARRAY_DOUBLE(white_pixels_astrobot15);
  } else if (s == 9) {
    setBlackColor(); PROCESS_PIXEL_ARRAY_DOUBLE(white_pixels_astrobot14);
  } else if (s == 10) {
    setBlackColor(); PROCESS_PIXEL_ARRAY_DOUBLE(white_pixels_astrobot13);
  } else if (s == 11) {
    setBlackColor(); PROCESS_PIXEL_ARRAY_DOUBLE(white_pixels_astrobot12);
  } else {
    setBlackColor(); PROCESS_PIXEL_ARRAY_DOUBLE(white_pixels_astrobot11);
  }
  return frame;
}

void clearScreen() {
  tft.fillScreen(ST7735_BLACK);
}

// ============================================================
// Melody player — non-blocking, driven by millis()
// ============================================================

int melodyPin;
const int (*melodyNotes)[3];
size_t melodyLen;
int melodyIndex;
unsigned long melodyPhaseStart;
bool melodyActive;
bool melodyPlaying;

void startMelody(int pin, const int notes[][3], size_t len) {
  melodyPin = pin;
  melodyNotes = notes;
  melodyLen = len;
  melodyIndex = 0;
  melodyActive = true;
  melodyPlaying = true;
  melodyPhaseStart = millis();
  tone(melodyPin, melodyNotes[0][0]);
}

void updateMelody() {
  if (!melodyActive || melodyIndex >= melodyLen) return;

  unsigned long now = millis();
  unsigned long elapsed = now - melodyPhaseStart;

  if (melodyPlaying) {
    if (elapsed >= melodyNotes[melodyIndex][1]) {
      noTone(melodyPin);
      if (melodyNotes[melodyIndex][2] > 0) {
        melodyPlaying = false;
        melodyPhaseStart = now;
      } else {
        melodyIndex++;
        if (melodyIndex >= melodyLen) {
          melodyActive = false;
        } else {
          melodyPhaseStart = now;
          tone(melodyPin, melodyNotes[melodyIndex][0]);
        }
      }
    }
  } else {
    if (elapsed >= melodyNotes[melodyIndex][2]) {
      melodyIndex++;
      if (melodyIndex >= melodyLen) {
        melodyActive = false;
      } else {
        melodyPlaying = true;
        melodyPhaseStart = now;
        tone(melodyPin, melodyNotes[melodyIndex][0]);
      }
    }
  }
}

bool isMelodyDone() {
  return !melodyActive;
}

// ============================================================
// State machine — manages eyes/clock/hearts/alarm
// ============================================================

State previousState = SHOW_DATE;
State currentState = SHOW_DATE;

unsigned long stateChangeMillis = 0;
const unsigned long stateChangeIntervalTimer = 5500;
const unsigned long stateChangeIntervalEye = 10000;

unsigned long animation_started = 0;
int animation_loop = 0;

// Alarm state — trigger, dismiss, auto-off
#if ALARM_ENABLED
bool alarmDismissedToday = false;
#endif

// ============================================================
// Main loop
// ============================================================

void loop() {
  // 1. Update melody (runs every tick, non-blocking)
  updateMelody();

  // Restart melody when it finishes during alarm (looping)
  #if ALARM_ENABLED
  if (currentState == ALARMING && isMelodyDone()) {
    startMelody(SPEAKER_PIN, midi1, countof(midi1));
  }
  #endif

  // 2. Read time and vibration sensor
  DateTime now = rtc.now();
  int vibrationValue = analogRead(VIBRATION_SENSOR);
  unsigned long currentMillis = millis();

  previousState = currentState;

  // 3. State transitions (priority order)
  if (vibrationValue > THRESHOLD) {
    Serial.println("vibration detected");
    #if ALARM_ENABLED
    if (currentState == ALARMING) {
      currentState = SHOW_EYES;
      alarmDismissedToday = true;
    } else
    #endif
    {
      currentState = VIBRATION_DETECTED;
    }
  } else {
    #if ALARM_ENABLED
    // Check alarm trigger
    if (currentState != ALARMING && !alarmDismissedToday &&
        now.hour() == ALARM_HOUR && now.minute() == ALARM_MINUTE &&
        now.second() < 5) {
      if (!WEEKDAYS_ONLY || (now.dayOfTheWeek() >= 1 && now.dayOfTheWeek() <= 5)) {
        currentState = ALARMING;
      }
    }

    // Normal transitions (skip when alarming)
    if (currentState != ALARMING) {
    #endif
      if (previousState == SHOW_EYES && currentMillis - stateChangeMillis >= stateChangeIntervalEye) {
        currentState = SHOW_DATE;
      } else if (previousState == SHOW_DATE && currentMillis - stateChangeMillis >= stateChangeIntervalTimer) {
        currentState = SHOW_EYES;
      } else if (previousState == VIBRATION_DETECTED && isMelodyDone()) {
        currentState = SHOW_EYES;
      }
    #if ALARM_ENABLED
    }

    // Auto-dismiss alarm after 60s
    if (currentState == ALARMING && currentMillis - stateChangeMillis >= 60000) {
      currentState = SHOW_EYES;
      alarmDismissedToday = true;
    }

    // Reset dismiss flag at midnight
    if (now.hour() == 0 && now.minute() == 0 && now.second() < 5) {
      alarmDismissedToday = false;
    }
    #endif
  }

  // 4. State entry — runs once when switching to a new state
  if (currentState != previousState) {
    if (previousState == VIBRATION_DETECTED || previousState == ALARMING) {
      noTone(melodyPin);
      melodyActive = false;
      melodyIndex = 0;
    }
    stateChangeMillis = currentMillis;
    animation_started = currentMillis;
    animation_loop = 0;
    clearScreen();

    switch (currentState) {
      #if ALARM_ENABLED
      case ALARMING:
        startMelody(SPEAKER_PIN, midi1, countof(midi1));
        printAlarm(now);
        break;
      #endif
      case VIBRATION_DETECTED:
        startMelody(SPEAKER_PIN, midi1, countof(midi1));
        animation_loop = drawHearts(animation_loop);
        break;
      case SHOW_EYES:
        animation_loop = drawEyes(animation_loop);
        break;
      case SHOW_DATE:
        printDate(now);
        break;
      default: break;
    }
  }

  // 5. Animation ticks — runs periodically based on animation_interval
  if (currentMillis - animation_started > animation_interval) {
    animation_started = currentMillis;
    animation_loop++;

    switch (currentState) {
      case VIBRATION_DETECTED:
        animation_loop = drawHearts(animation_loop);
        break;
      case SHOW_EYES:
        animation_loop = drawEyes(animation_loop);
        break;
      default: break;
    }
  }
}
